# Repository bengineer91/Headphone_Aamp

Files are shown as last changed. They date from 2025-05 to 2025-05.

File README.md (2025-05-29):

Opamp based headphone amplifier. 

**Digital Side**

Momentary push button feeds a schmitt trigger and D flip flop to turn the board on and off. A USB-C connector with 5.1k resistors on the CC pins sets it up for 5V 3A max - this is mainly because I couldn't find a sufficiently simple USB-C PD Sink IC that I liked. Even the simple ones seemed overly complex so my conclusion is I'm not the target audience of where the industry is headed.

**Analog Side**

Isolated DC/DC converter takes 5V in and spits out +/-12V. This then feeds through an LDO to regulate the split rails at roughly +/-10V. Audio path is a 10k potentiometer, OPA1656 provides high and low pass filtering along with gain, then parallel stages of OPA1678 provide the output stage.

Sound quality is excellent although I already have a list of issues and improvements for next time. [Fixed] indicates the files uploaded here have this incorporated. I don't have a scope to make any measurements - only thing I checked was voltage rails and DC offset with my multimeter.

1. [Fixed] Connect LDO enable to VIN. (I had to make a daughterboard on the revision I built).
2. Anti-pop circuit on output.
3. [Fixed] Add cap (C35) so the on/off circuit defaults to off at power application.
4. Add switchable dummy load for testing before connecting headphones.
5. Trimpot for LED brightness.
6. Adjustable gain

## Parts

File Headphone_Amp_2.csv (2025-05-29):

Reference | Value | Part Number | Qty | DNP | Footprint | Datasheet | Voltage
C1,C8 | 0.01u | KGM21NR71H103KT | 2 |  | Capacitor_SMD:C_0805_2012Metric_Pad1.18x1.45mm_HandSolder | ~ | 50V
C2 | 4.7u | GRM21BC71H475KE11K | 1 |  | Capacitor_SMD:C_0805_2012Metric_Pad1.18x1.45mm_HandSolder | ~ | 50V
C3,C15 | 0.1u | 0805YC104MAT2A | 2 |  | Capacitor_SMD:C_0805_2012Metric_Pad1.18x1.45mm_HandSolder | ~ | 35V
C4,C34 | 1000p | C0805C102K5RACTU | 2 |  | 1_User_Library:C_0805_2012Metric_HandSolder | ~ | Vol
C5,C6,C13,C14 | 10u | CL31B106KAHNNNE | 4 |  | Capacitor_SMD:C_1206_3216Metric_Pad1.33x1.80mm_HandSolder | ~ | 25V
C7,C9 | 4.7u | GRM21BR71A475KE51L | 2 |  | Capacitor_SMD:C_0805_2012Metric_Pad1.18x1.45mm_HandSolder | ~ | 10V
C10 | 1n | C0805C102KDRACAUTO | 1 |  | 1_User_Library:C_0805_2012Metric_HandSolder | ~ | 1kV
C11,C12 | 10n | C0805C103K5RACTU | 2 |  | 1_User_Library:C_0805_2012Metric_HandSolder | ~ | 50V
C16,C18,C21,C23,C26,C28 | 100n | GCM21BR71H104KA37L | 6 |  | 1_User_Library:C_0805_2012Metric_HandSolder | ~ | 50V
C17,C19,C20,C22,C25,C30,C32,C33 | 1u | 0805YC105KAT2A | 8 |  | 1_User_Library:C_0805_2012Metric_HandSolder | ~ | 16V
C24,C27,C29,C31 | 68p | C0805C680K5RACAUTO | 4 |  | 1_User_Library:C_0805_2012Metric_HandSolder | ~ | 50V
D1 | MMSZ5238BT1G | MMSZ5238BT1G | 1 |  | Diode_SMD:D_SOD-123 | ~
D2,D3,D4,D5,D6 | LED | APT2012PGW | 5 |  | LED_SMD:LED_0805_2012Metric_Pad1.15x1.40mm_HandSolder | ~
H1,H2,H3,H4 | MountingHole | 24883 | 4 |  | 1_User_Library:Keystone_M3_Standoff | ~
J1,J5 | Conn_02x01 | FTS-102-01-L-S | 2 |  | Connector_PinHeader_1.27mm:PinHeader_1x02_P1.27mm_Vertical,Connector_PinHeader_1.27mm:PinHeader_2x01_P1.27mm_Vertical | ~
J2 | USB4125-GF-A-0190 | USB4125-GF-A-0190 | 1 |  | 1_User_Library:CONN6_125-GF-A-0190_GCT | USB4125-GF-A-0190
J3 | PJRAN2X1U01AUX | PJRAN2X1U01AUX | 1 |  | 1_User_Library:CONN6_984x394_SWC_BS | PJRAN2X1U01AUX
J4 | Conn_01x04 | FTS-104-01-L-S | 1 |  | Connector_PinHeader_1.27mm:PinHeader_1x04_P1.27mm_Vertical | ~
J6,J7 | Conn_02x02_Odd_Even | FTS-102-01-L-D | 2 |  | Connector_PinHeader_1.27mm:PinHeader_2x02_P1.27mm_Vertical | ~
J8 | SJ-63063B | SJ-63063B | 1 |  | 1_User_Library:CUI_SJ-63063B
L1 | 6.8u | MLZ2012N6R8LT000 | 1 |  | 1_User_Library:R_0805_2012Metric_HandSolder | ~
Q1 | IRF7324 | IRF7324 | 1 |  | Package_SO:SOIC-8_3.9x4.9mm_P1.27mm | http://www.infineon.com/dgdl/irf7324pbf.pdf?fileId=5546d462533600a4015355f5f0861b4b
R1,R32,R33,R35,R36 | 150 | CRCW0805150RFKEA | 5 |  | 1_User_Library:R_0805_2012Metric_HandSolder | ~
R2,R14,R15,R17,R21,R22,R24,R25,R26,R27,R28,R29,R30,R31 | 10K,10k | CRCW080510K0FKEA | 14 |  | 1_User_Library:R_0805_2012Metric_HandSolder | ~
R3,R7 | 47 | CRCW080547R0FKEA | 2 |  | 1_User_Library:R_0805_2012Metric_HandSolder | ~
R4,R5 | 5.1K | CRCW08055K10FKEA | 2 |  | 1_User_Library:R_0805_2012Metric_HandSolder | ~
R6,R10,R11 | 0 | CRCW08050000Z0EA | 3 | DNP | 1_User_Library:R_0805_2012Metric_HandSolder | ~
R8,R9 | 0 | CRCW08050000Z0EA | 2 |  | 1_User_Library:R_0805_2012Metric_HandSolder | ~
R12 | 330 | CRCW0805330RFKEA | 1 |  | 1_User_Library:R_0805_2012Metric_HandSolder | ~
R13 | 84.5k | CRCW080584K5FKEA | 1 |  | 1_User_Library:R_0805_2012Metric_HandSolder | ~
R16 | 75k | CRCW080575K0FKEA | 1 |  | 1_User_Library:R_0805_2012Metric_HandSolder | ~
R18,R19,R20,R23 | 1 | CRCW08051R00FKEA | 4 |  | 1_User_Library:R_0805_2012Metric_HandSolder | ~
R34 | RK09L12B0A4S | RK09L12B0A4S | 1 |  | 1_User_Library:RK09L12B0A4S_AAL | RK09L12B0A4S
SW1 | BB15AH-FA | BB15AH-FA | 1 |  | 1_User_Library:BB16AH | ~
TP1,TP2,TP3,TP4,TP5,TP6,TP7,TP8,TP9,TP10,TP11 | 5020 | 5020 | 11 |  | 1_User_Library:KEYSTONE_5020
U1 | SN74LVC1G74DCTR | SN74LVC1G74DCTR | 1 |  | 1_User_Library:DCT0008A_L | SN74LVC1G74DCTR
U2 | PCN2-S5-D12-S | PCN2-S5-D12-S | 1 |  | 1_User_Library:CONV_PCN2-S5-D12-S
U3 | TPS7A39 | TPS7A3901DSCR | 1 |  | Package_SON:Texas_S-PVSON-N10 | https://www.ti.com/lit/ds/symlink/tps7a39.pdf
U4 | 74LVC1G17 | SN74LVC1G17DBVR | 1 |  | Package_TO_SOT_SMD:SOT-23-5 | https://www.ti.com/lit/ds/symlink/sn74lvc1g17.pdf
U5,U6 | OPA1678 | OPA1678IDR | 2 |  | Package_SO:SOIC-8_3.9x4.9mm_P1.27mm | http://www.ti.com/lit/ds/symlink/opa1678.pdf
U7 | OPA1656ID | OPA1656IDR | 1 |  | Package_SO:SOIC-8_3.9x4.9mm_P1.27mm | https://www.ti.com/lit/ds/symlink/opa1656.pdf
U8 | TVS2200DRV | TVS2200DRV | 1 |  | Package_SON:WSON-6-1EP_2x2mm_P0.65mm_EP1x1.6mm | http://www.ti.com/lit/ds/symlink/tvs2200.pdf

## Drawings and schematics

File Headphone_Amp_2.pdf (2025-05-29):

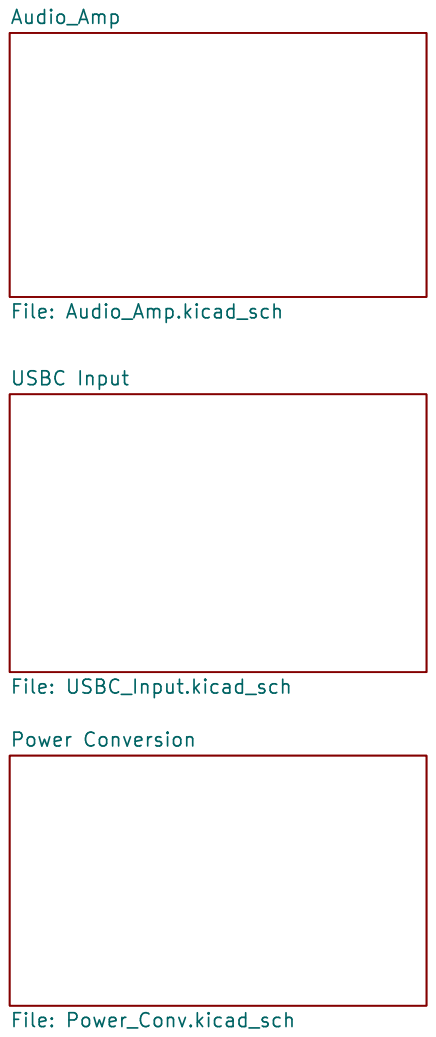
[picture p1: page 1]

Audio_Amp File: Audio_Amp.kicad_sch Power Conversion File: Power_Conv.kicad_sch

Id: 1/4 Title: File: Headphone_Amp_2.kicad_sch Sheet: /

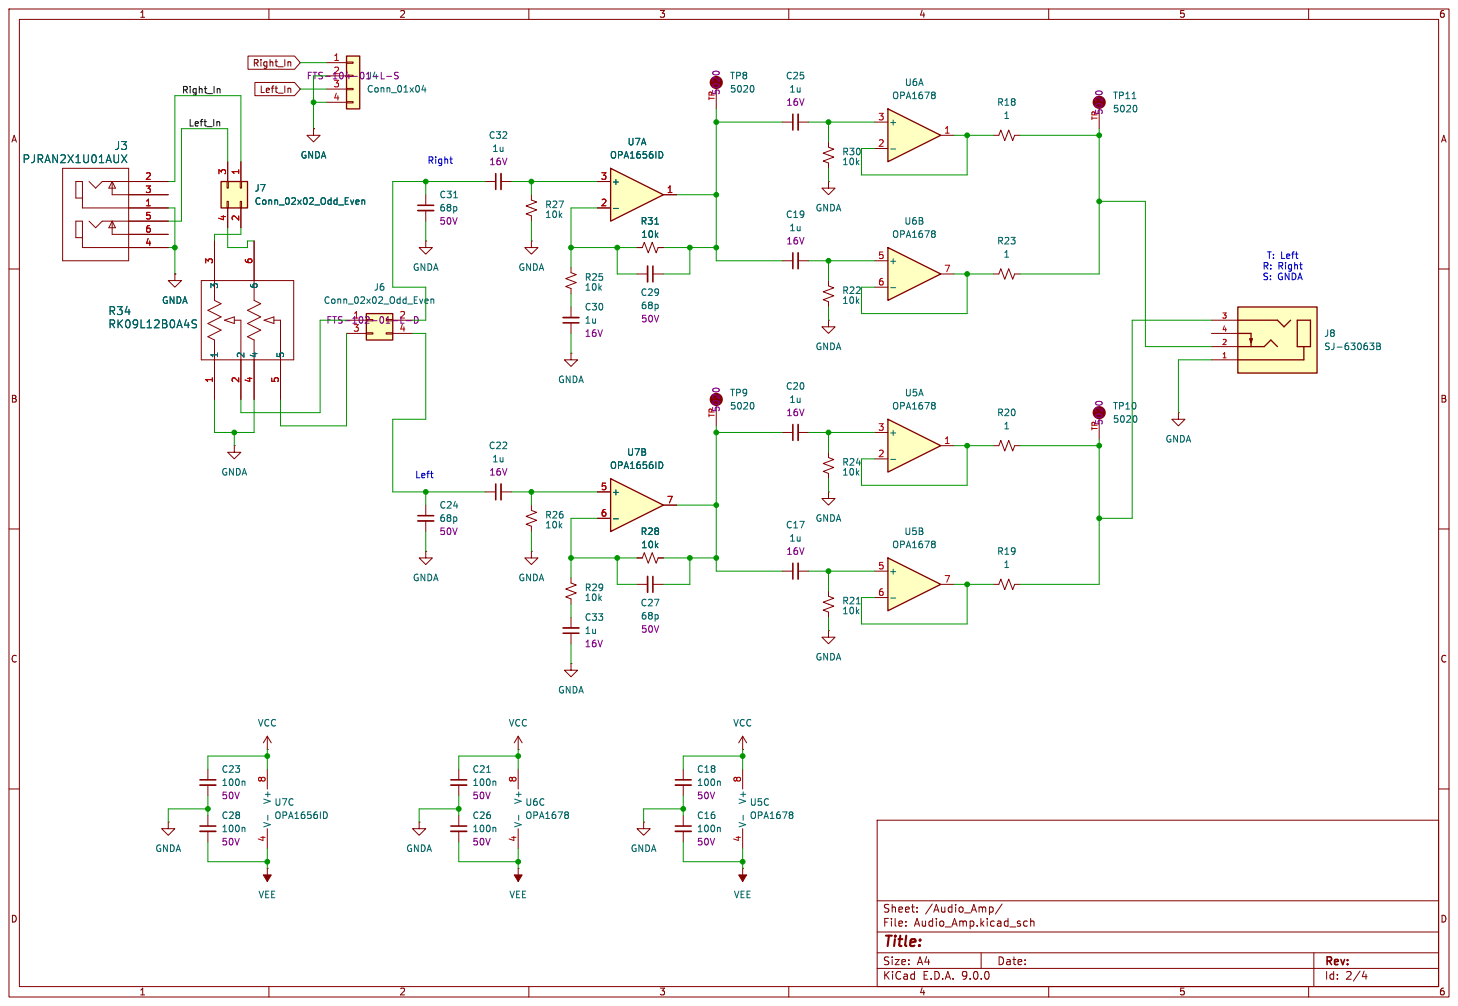
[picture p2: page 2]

Id: 2/4 Title: File: Audio_Amp.kicad_sch Sheet: /Audio_Amp/ V+

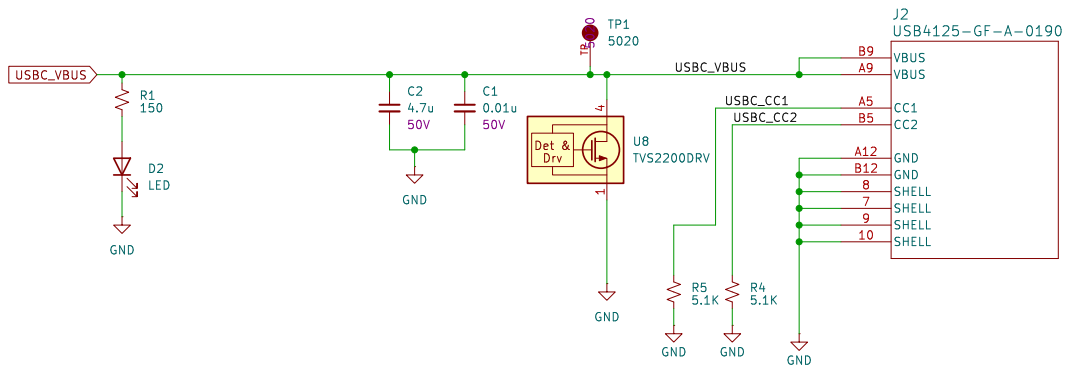
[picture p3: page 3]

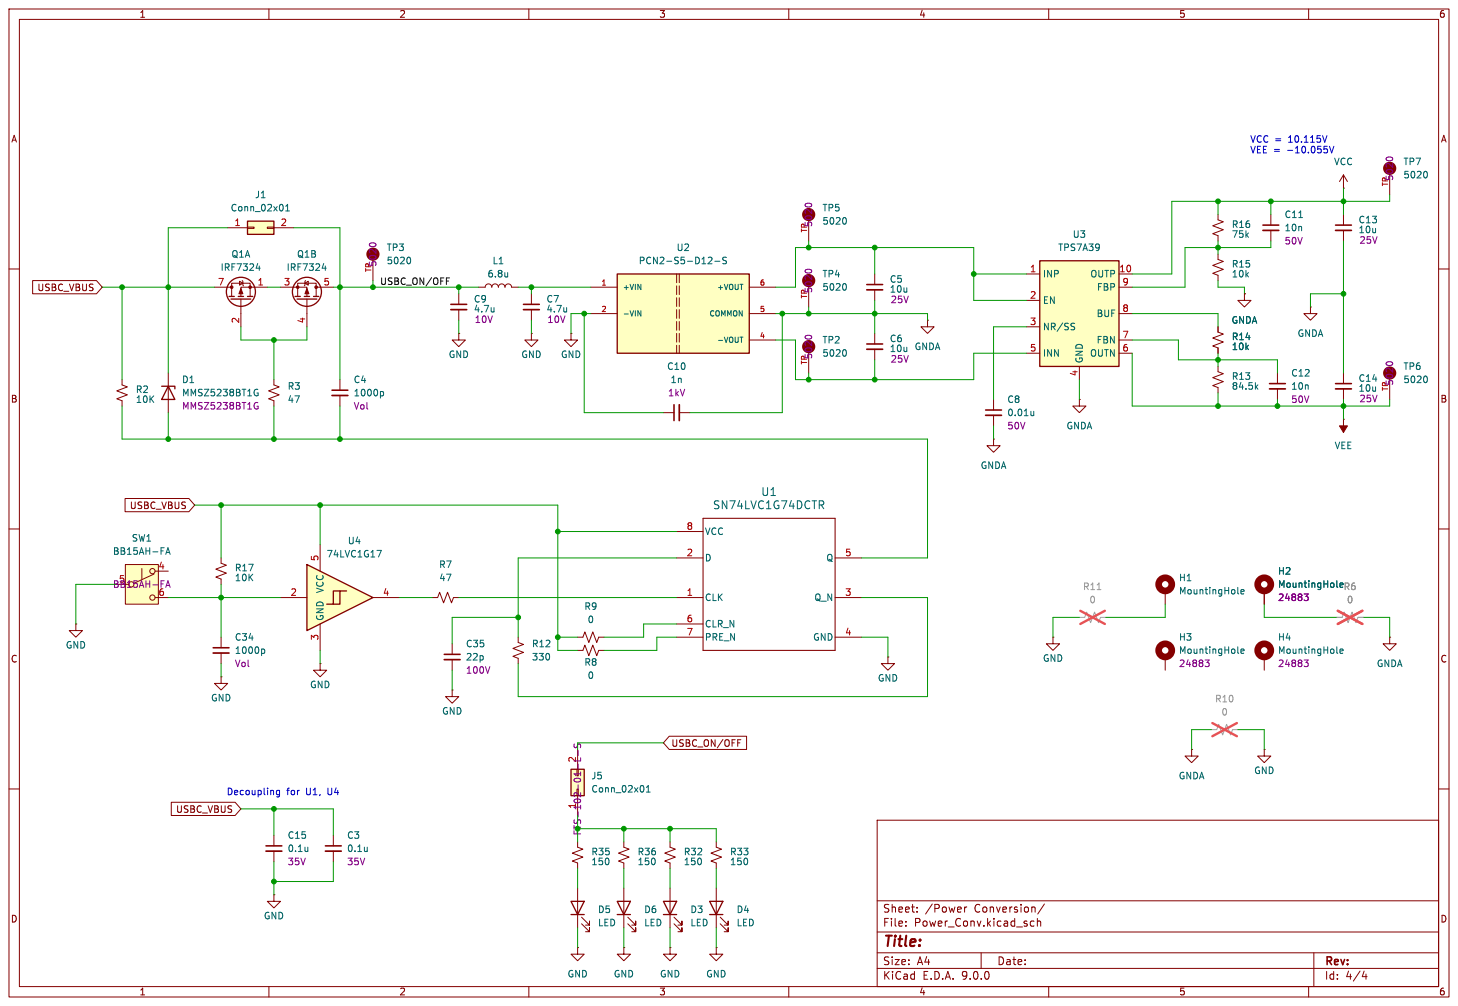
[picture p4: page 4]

4 OUTP 10 FBP 9 BUF 8 FBN 7 OUTN 6 U3 TPS7A39 R6

INP 1 EN 2 NR/SS 3

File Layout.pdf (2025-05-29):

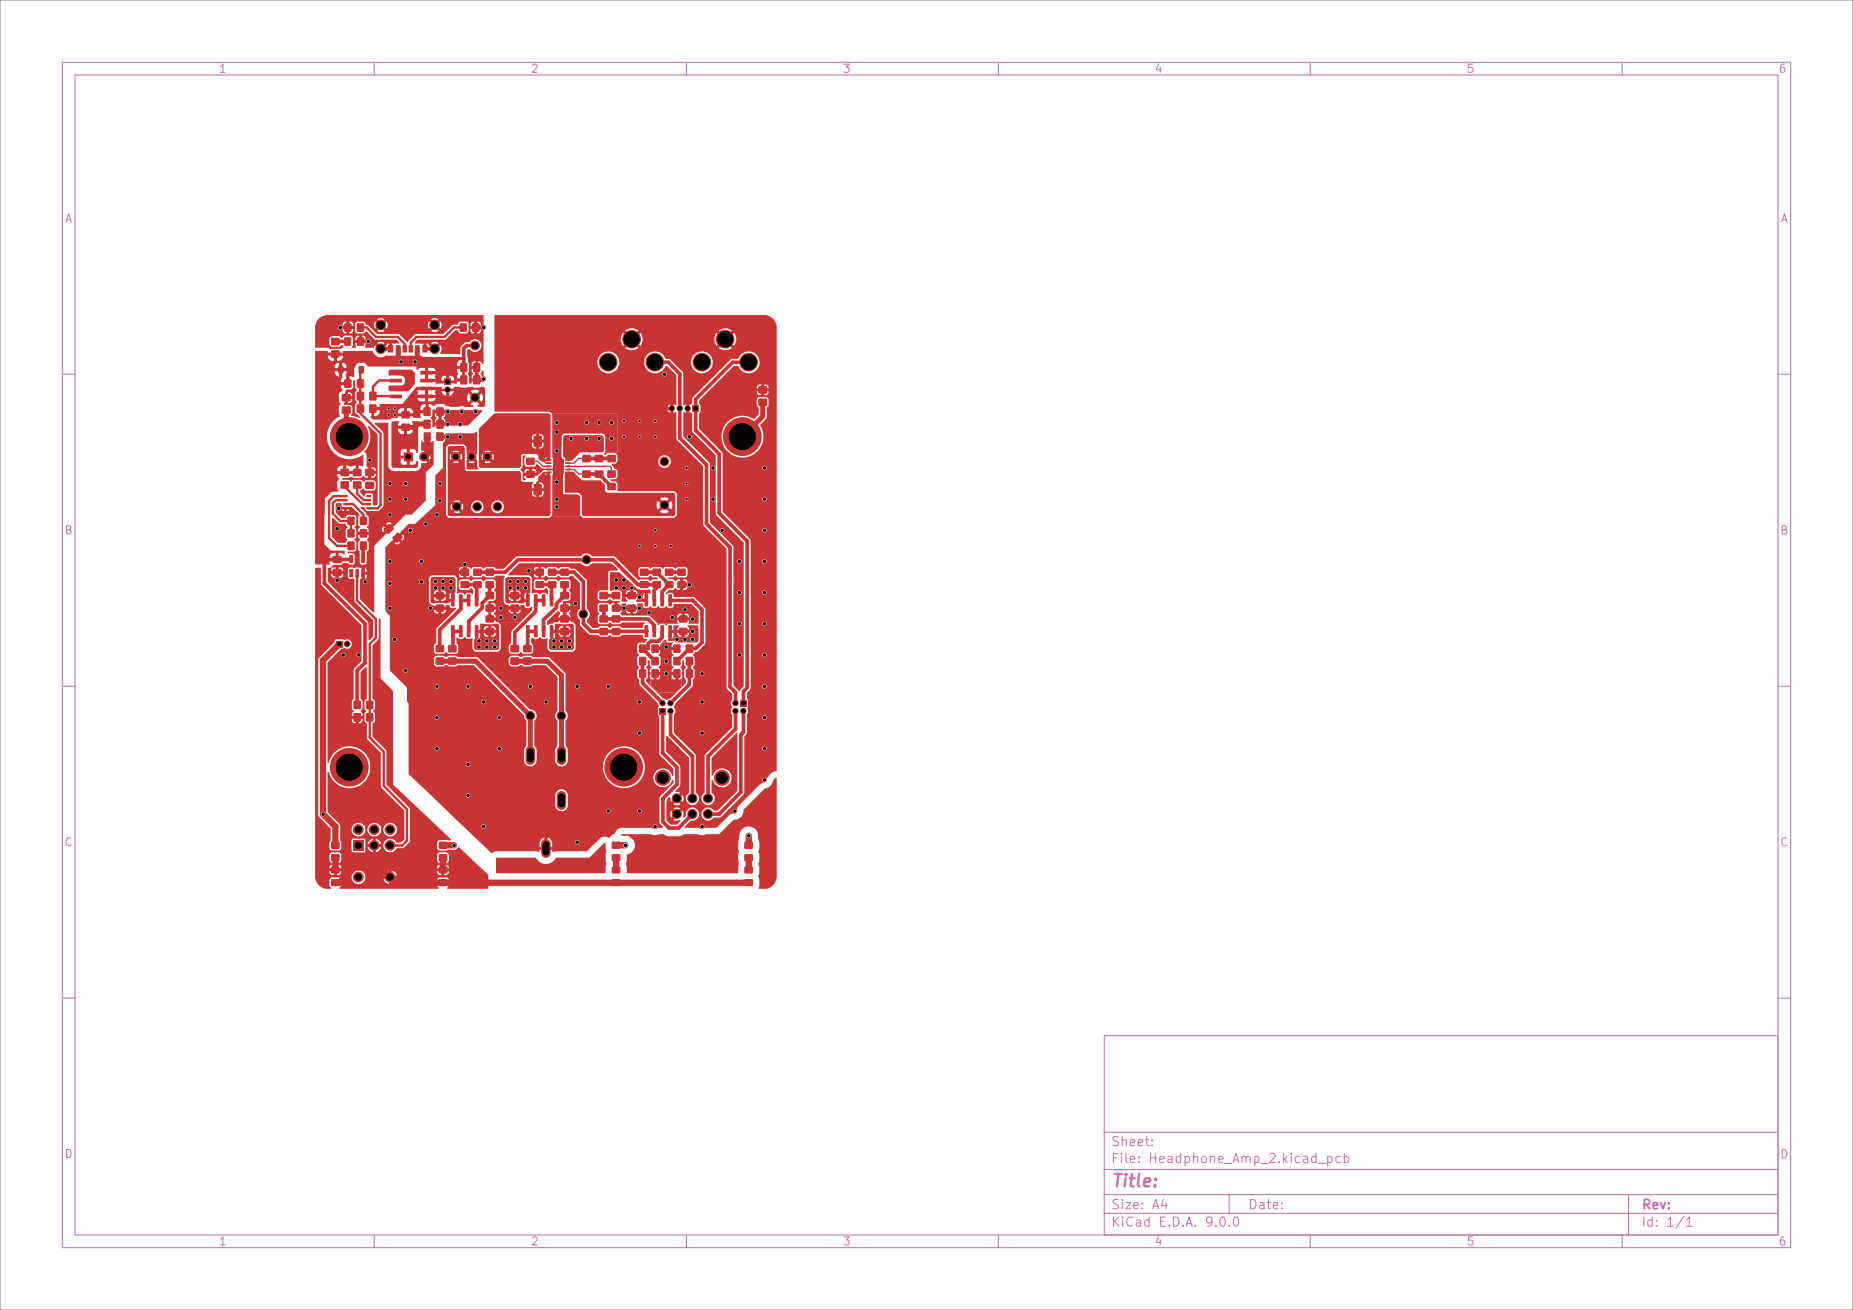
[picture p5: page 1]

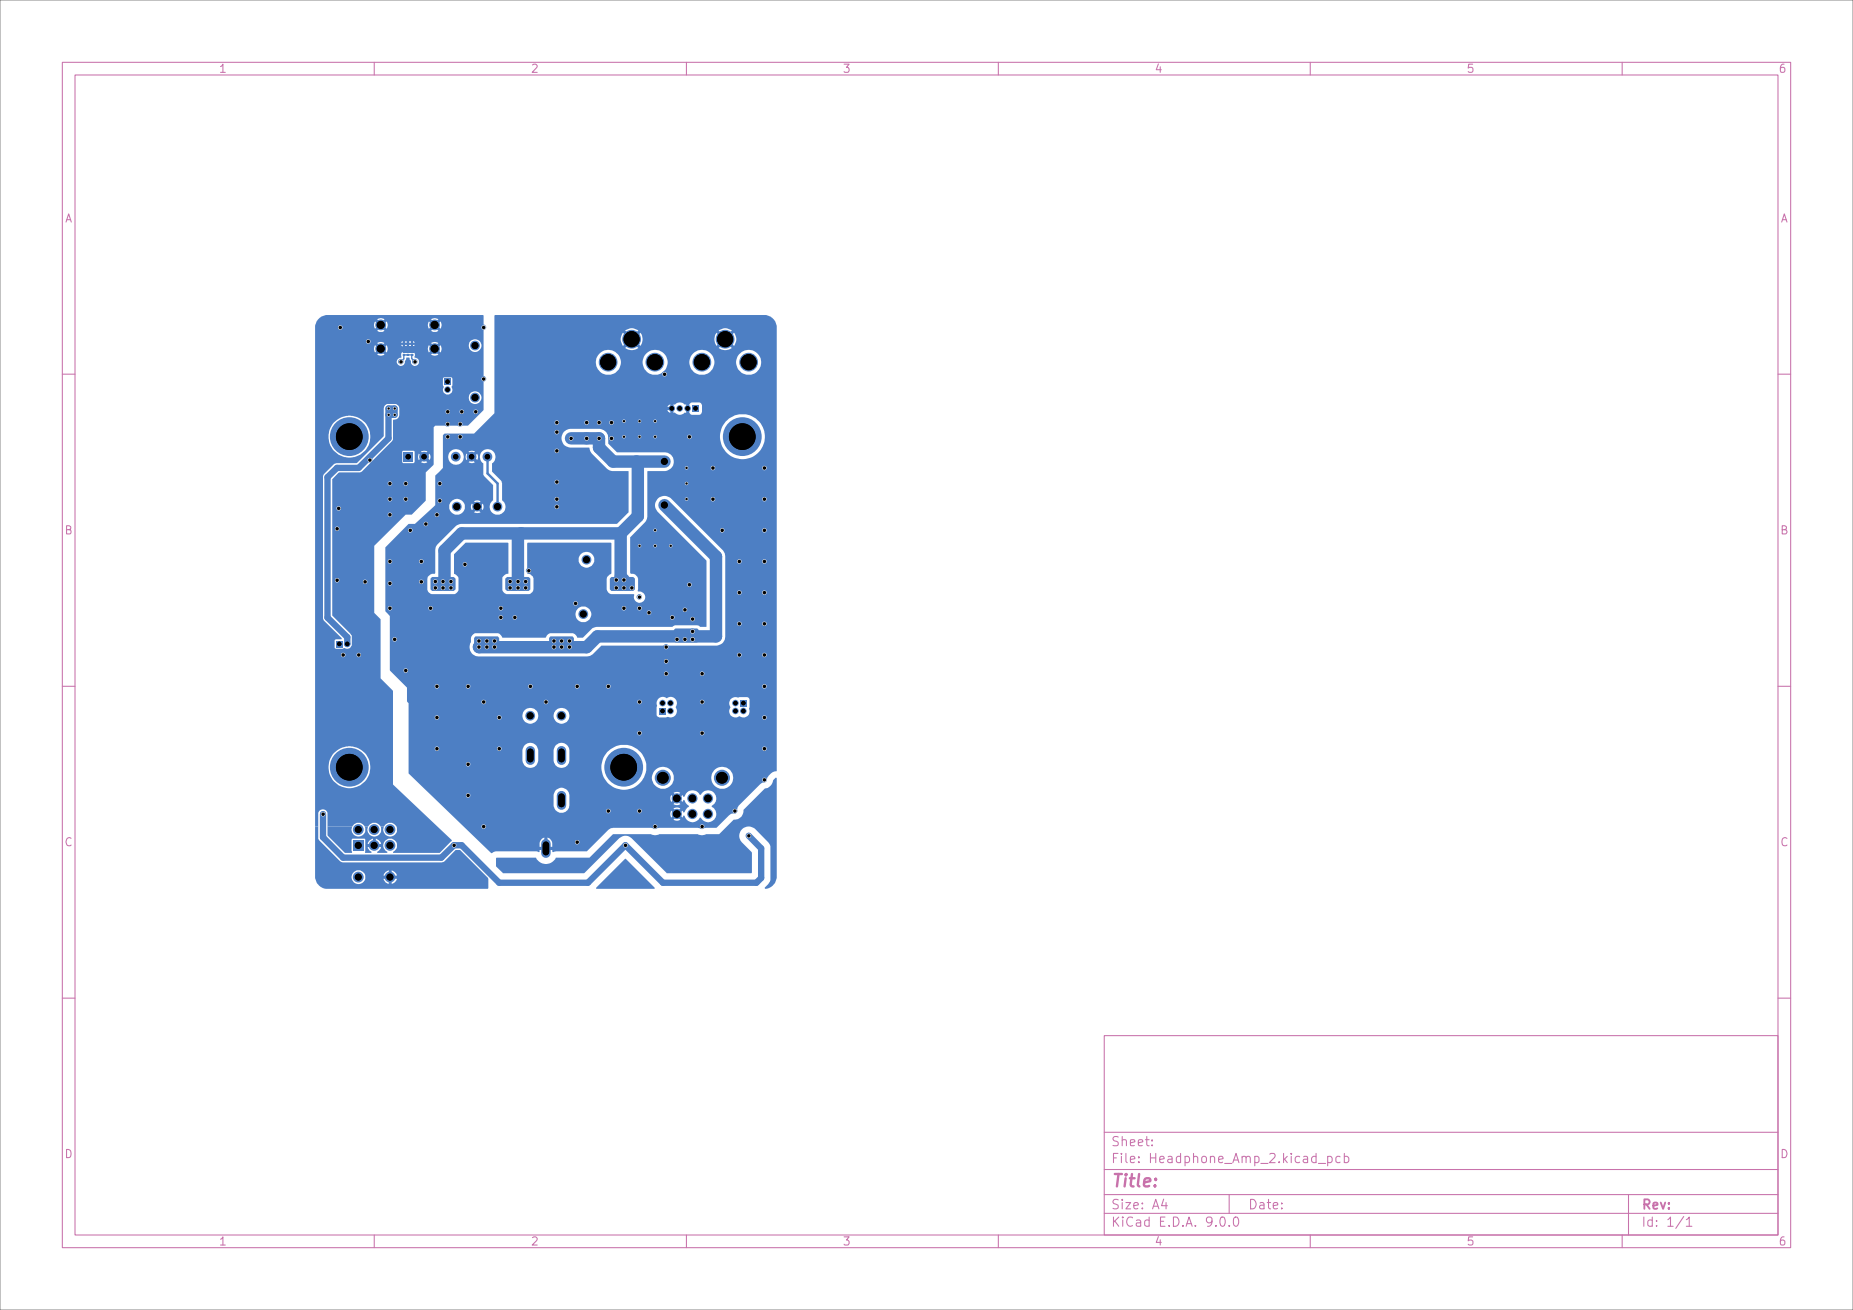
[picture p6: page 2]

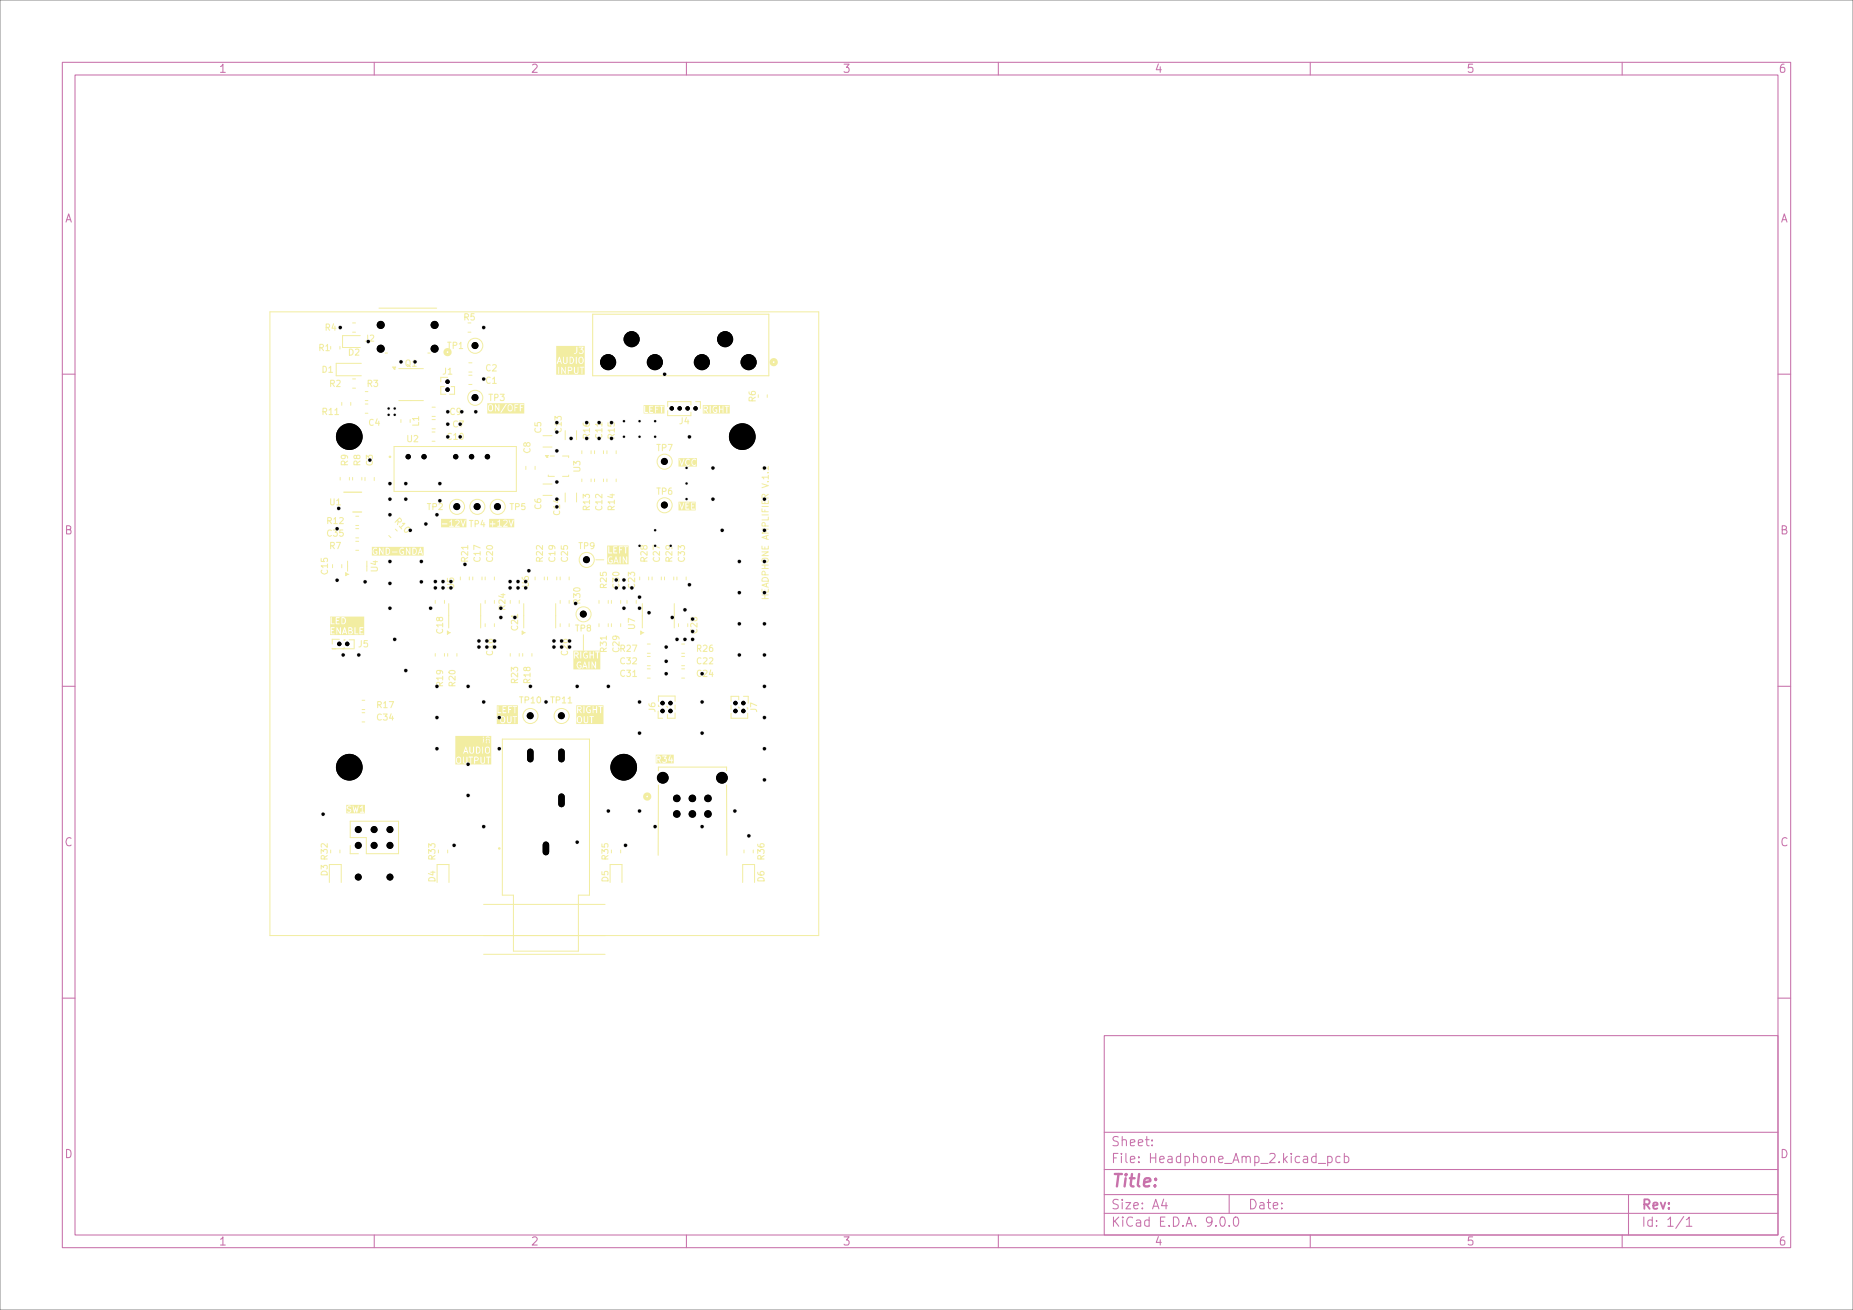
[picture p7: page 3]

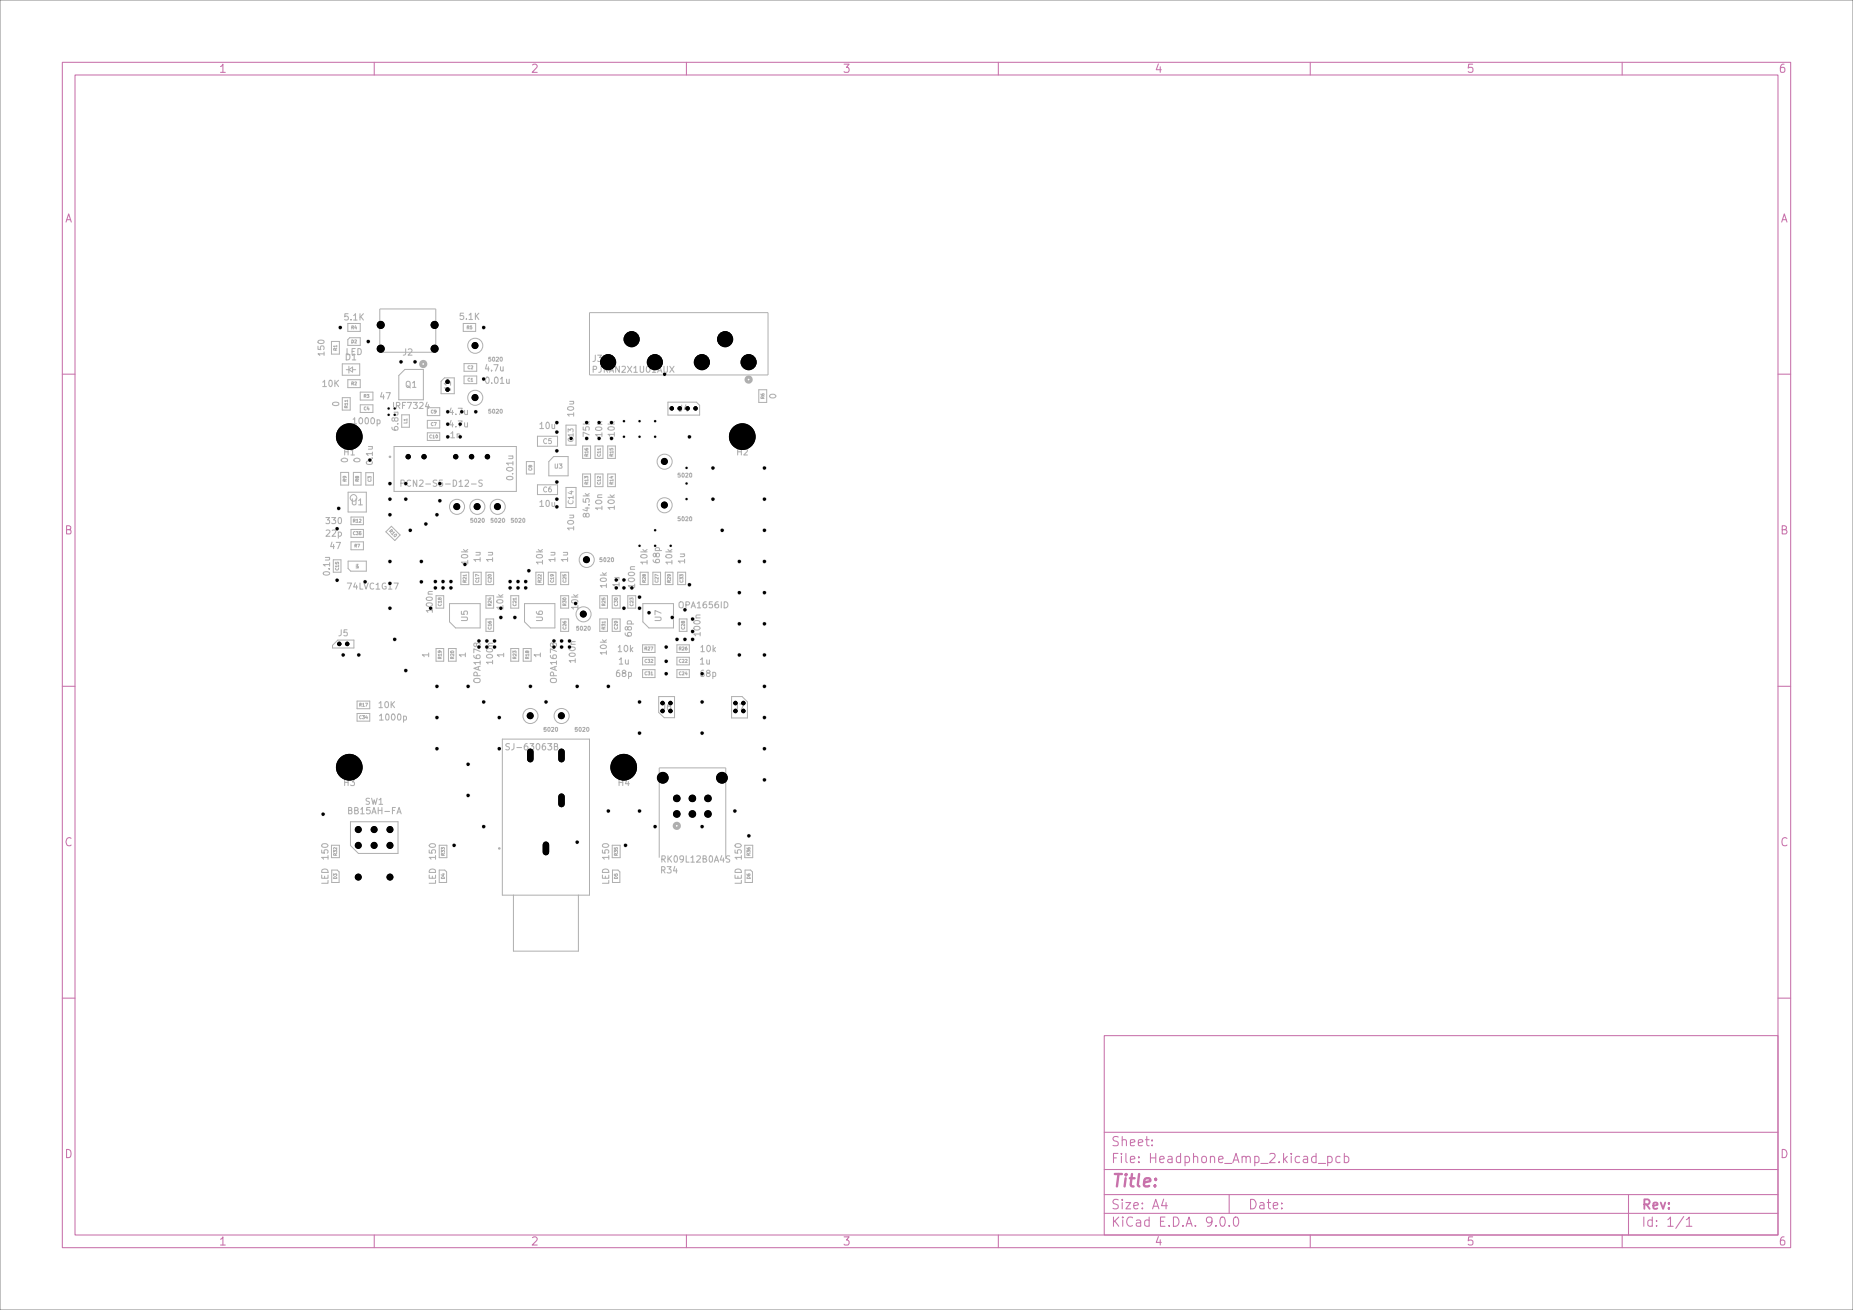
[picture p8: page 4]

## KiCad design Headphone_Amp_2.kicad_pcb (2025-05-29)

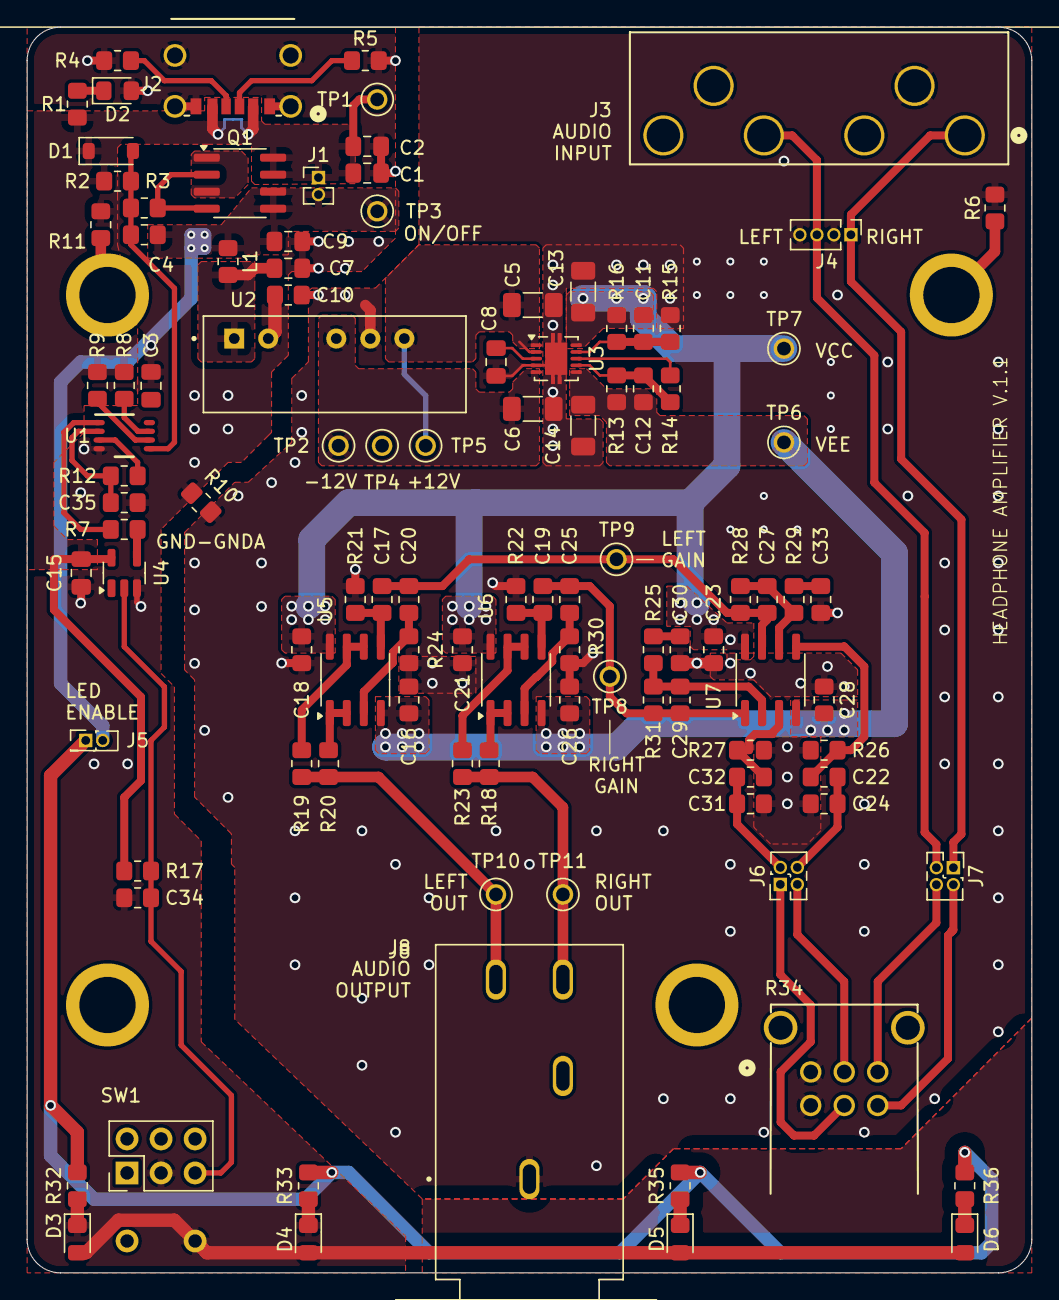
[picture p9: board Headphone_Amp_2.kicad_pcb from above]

Board: 2 copper layers, 75.0 x 93.0 mm, 111 parts (1 on the bottom side), 59 nets.

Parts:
C1, C8: 0.01u; C_0805_2012Metric_Pad1.18x1.45mm_HandSolder
C2, C7, C9: 4.7u; C_0805_2012Metric_Pad1.18x1.45mm_HandSolder
C3, C15: 0.1u; C_0805_2012Metric_Pad1.18x1.45mm_HandSolder
C4, C34: 1000p; C_0805_2012Metric_HandSolder
C5, C6, C13, C14: 10u; C_1206_3216Metric_Pad1.33x1.80mm_HandSolder
C10: 1n; C_0805_2012Metric_HandSolder
C11, C12: 10n; C_0805_2012Metric_HandSolder
C16, C18, C21, C23, C26, C28: 100n; C_0805_2012Metric_HandSolder
C17, C19, C20, C22, C25, C30, C32, C33: 1u; C_0805_2012Metric_HandSolder
C24, C27, C29, C31: 68p; C_0805_2012Metric_HandSolder
C35: 22p; C_0805_2012Metric_HandSolder
D1: MMSZ5238BT1G; D_SOD-123
D2, D3, D4, D5, D6: LED; LED_0805_2012Metric_Pad1.15x1.40mm_HandSolder
H1, H2, H3, H4: MountingHole; Keystone_M3_Standoff
J1: Conn_02x01; PinHeader_1x02_P1.27mm_Vertical
J2: USB4125-GF-A-0190; CONN6_125-GF-A-0190_GCT
J3: PJRAN2X1U01AUX; CONN6_984x394_SWC_BS
J4: Conn_01x04; PinHeader_1x04_P1.27mm_Vertical
J5: Conn_02x01; PinHeader_2x01_P1.27mm_Vertical
J6, J7: Conn_02x02_Odd_Even; PinHeader_2x02_P1.27mm_Vertical
J8: SJ-63063B; CUI_SJ-63063B
L1: 6.8u; R_0805_2012Metric_HandSolder
Q1: IRF7324; SOIC-8_3.9x4.9mm_P1.27mm
R1, R32, R33, R35, R36: 150; R_0805_2012Metric_HandSolder
R2, R17: 10K; R_0805_2012Metric_HandSolder
R3, R7: 47; R_0805_2012Metric_HandSolder
R4, R5: 5.1K; R_0805_2012Metric_HandSolder
R6, R8, R9, R10, R11: 0; R_0805_2012Metric_HandSolder
R12: 330; R_0805_2012Metric_HandSolder
R13: 84.5k; R_0805_2012Metric_HandSolder
R14, R15, R21, R22, R24, R25, R26, R27, R28, R29, R30, R31: 10k; R_0805_2012Metric_HandSolder
R16: 75k; R_0805_2012Metric_HandSolder
R18, R19, R20, R23: 1; R_0805_2012Metric_HandSolder
R34: RK09L12B0A4S; RK09L12B0A4S_AAL
SW1: BB15AH-FA; BB16AH
TP1, TP2, TP3, TP4, TP5, TP6, TP7, TP8, TP9, TP10, TP11: 5020; KEYSTONE_5020
U1: SN74LVC1G74DCTR; DCT0008A_L
U2: PCN2-S5-D12-S; CONV_PCN2-S5-D12-S
U3: TPS7A39; Texas_S-PVSON-N10
U4: 74LVC1G17; SOT-23-5
U5, U6: OPA1678; SOIC-8_3.9x4.9mm_P1.27mm
U7: OPA1656ID; SOIC-8_3.9x4.9mm_P1.27mm
U8: TVS2200DRV; WSON-6-1EP_2x2mm_P0.65mm_EP1x1.6mm

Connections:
/USBC Input/USBC_CC1: J2.A5 (CC1), R5.1
/USBC Input/USBC_CC2: J2.B5 (CC2), R4.1
GND: C1.2, C2.2, C3.2, C7.2, C9.2, C10.1, C15.2, C34.2, C35.2, D2.2 (A), D3.1 (K), D4.1 (K), D5.1 (K), D6.1 (K), J2.7 (SHELL), J2.8 (SHELL), J2.9 (SHELL), J2.10 (SHELL), J2.A12 (GND), J2.B12 (GND), R4.2, R5.2, R10.2, R11.1, SW1.5 (B), U1.4 (GND), U2.2 (-VIN), U4.3 (GND), U8.1 (GND), U8.2 (GND), U8.3 (GND), U8.7 (GND)
GNDA: C5.2, C6.1, C8.2, C10.2, C13.2, C14.1, C16.1, C18.2, C21.2, C23.2, C24.2, C26.1, C28.1, C30.1, C31.2, C33.1, J3.1, J3.4, J4.2, J4.4, J8.1, R6.2, R10.1, R15.1, R21.1, R22.1, R24.1, R26.1, R27.1, R30.1, R34.1, R34.4, TP4.TP, U2.5 (COMMON), U3.4 (GND), U3.11 (GND)
Left_In: J3.5, J4.3, J7.3
unnamed: C17.1, C20.1, C27.1, R28.2, TP9.TP, U7.7
unnamed: C19.1, C25.1, C29.1, R31.2, TP8.TP, U7.1
unnamed: C30.2, R25.1
unnamed: C33.2, R29.1
unnamed: C4.2, D1.2 (A), R2.2, R3.1, U1.5 (Q)
unnamed: D2.1 (K), R1.2
unnamed: D3.2 (A), R32.2
unnamed: D4.2 (A), R33.2
unnamed: D5.2 (A), R35.2
unnamed: D6.2 (A), R36.2
unnamed: H1.1, R11.2
unnamed: H2.1, R6.1
unnamed: J5.1, R32.1, R33.1, R35.1, R36.1
unnamed: J6.1, R34.2
unnamed: C31.1, C32.1, J6.2
unnamed: J6.3, R34.5
unnamed: C22.1, C24.1, J6.4
unnamed: J7.2, R34.3
unnamed: J7.4, R34.6
unnamed: J8.2, R18.1, R23.1, TP11.TP
unnamed: J8.3, R19.1, R20.1, TP10.TP
unnamed: Q1.2 (G1), Q1.4 (G2), R3.2
unnamed: Q1.1 (S1), Q1.3 (S2)
unnamed: R7.2, U4.4
unnamed: C34.1, R17.2, SW1.6 (C), U4.2
unnamed: R7.1, U1.1 (CLK)
unnamed: R9.2, U1.6 (CLR_N)
unnamed: C35.1, R12.1, U1.2 (D)
unnamed: R8.2, U1.7 (PRE_N)
unnamed: R12.2, U1.3 (Q_N)
unnamed: C7.1, L1.2, U2.1 (+VIN)
unnamed: C5.1, TP5.TP, U2.6 (+VOUT), U3.1 (INP), U3.2 (EN)
unnamed: C6.2, TP2.TP, U2.4 (-VOUT), U3.5 (INN)
unnamed: R14.2, U3.8 (BUF)
unnamed: C12.1, R13.2, R14.1, U3.7 (FBN)
unnamed: C11.2, R15.2, R16.1, U3.9 (FBP)
unnamed: C8.1, U3.3 (NR/SS)
unnamed: C20.2, R24.2, U5.3 (+)
unnamed: R20.2, U5.1, U5.2 (-)
unnamed: C17.2, R21.2, U5.5 (+)
unnamed: R19.2, U5.6 (-), U5.7
unnamed: C25.2, R30.2, U6.3 (+)
unnamed: R18.2, U6.1, U6.2 (-)
unnamed: C19.2, R22.2, U6.5 (+)
unnamed: R23.2, U6.6 (-), U6.7
unnamed: C32.2, R27.2, U7.3 (+)
unnamed: C29.2, R25.2, R31.1, U7.2 (-)
unnamed: C22.2, R26.2, U7.5 (+)
unnamed: C27.2, R28.1, R29.2, U7.6 (-)
Right_In: J3.2, J4.1, J7.1
USBC_ON/OFF: C4.1, C9.1, J1.2, J5.2, L1.1, Q1.5 (D2), Q1.6 (D2), TP3.TP
USBC_VBUS: C1.1, C2.1, C3.1, C15.1, D1.1 (K), J1.1, J2.A9 (VBUS), J2.B9 (VBUS), Q1.7 (D1), Q1.8 (D1), R1.1, R2.1, R8.1, R9.1, R17.1, TP1.TP, U1.8 (VCC), U4.5 (VCC), U8.4 (IN), U8.5 (IN), U8.6 (IN)
VCC: C11.1, C13.1, C18.1, C21.1, C23.1, R16.2, TP7.TP, U3.10 (OUTP), U5.8 (V+), U6.8 (V+), U7.8 (V+)
VEE: C12.2, C14.2, C16.2, C26.2, C28.2, R13.1, TP6.TP, U3.6 (OUTN), U5.4 (V-), U6.4 (V-), U7.4 (V-)
